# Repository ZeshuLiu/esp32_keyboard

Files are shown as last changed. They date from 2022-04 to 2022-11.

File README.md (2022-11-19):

# 使用esp32为控制器的机械键盘

## **JOKER60**
`Joker 60` 
### **简介**
Joker60是一把poker配列61键键盘，具有一个fn键和一个pn键。
fn键用于输入第二层的键值，如<kbd>F1</kbd>、<kbd>ESC</kbd>（当左上角键被设置为<kbd>`</kbd>时）\
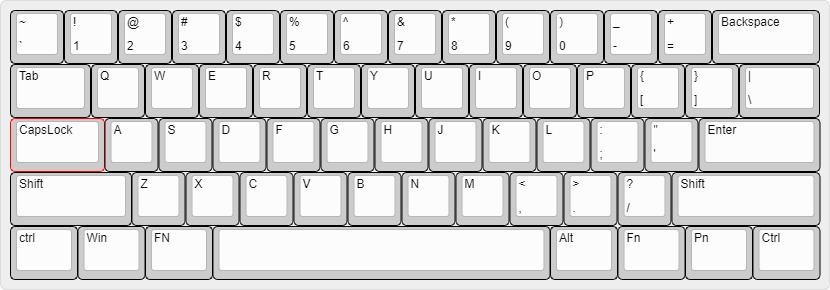
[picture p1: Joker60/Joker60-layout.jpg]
JOKER60 Layout
\
OLED屏幕可以显示当前模式，fn键状态。并且具有每30分钟提醒休息的功能，也可以自己修改源代码进行配置\
具有外接电池位置(PCB上B+、GND) 、外接LED灯或其他部件位置(x_LED)和i2c总线接口（*OLED屏幕使用中、可以串联其他不同地址的i2c设备同时使用*）

## **JOKER60 v2**
`Joker60 v2` 
### **简介**
外形与Joker60完全一致，大部分零件均通用。\
Joker60换用了ch9329芯片，可以支持媒体键（音量增加、减小等）。\
电路板进行了大面积敷铜，使用Kicad进行绘制，工程文件在Joker60_v2文件夹内。\
电路部分经过重新设计可以支持常驻型的usb拓展模块（详见Joker60_v2\usb_ext）并且可以板载电池。\
大小写指示灯更换了位置。

## **MASTER YODA**
`Master Yoda` 
### **简介**
一个小的键盘，可以用来打游戏等。

---
## **如何使用**
## **所需工具**
1. **电烙铁及焊锡等** ***必须***\
    推荐使用可调温电烙铁，普通电烙铁也可以。尽量选择头部比较尖锐的烙铁，方便焊接小零件。*有些元件非常小，因此建议先学习电烙铁使用方法，不要一上来就焊接*
2. **螺丝刀** ***必须***\
    一把3.5mm十字花螺丝刀足够
3. **万用表** ***可选***\
    推荐购买一个万用表，可以方便得检查焊接是否正确。没有也不影响正常组装，但是一旦出现问题难以排查。*万用表质量不需要非常好，便宜的就能够胜任*
4. **镊子** ***可选但是强烈推荐***\
    部分零件非常小，除非你的手特别灵活或者你特别闲脾气又好否则没有镊子你会气死。
5. **小刀** ***可选***\
    用来修整3D打印带来的毛边等。小号的壁纸刀最好。
6. **电线** ***v1.0版本必须***\
    用来飞线。建议使用26AWG粗细的。
7. **BOM表上的其他零件** ***必须***\
    [JOKER60 BOM](https://github.com/LiuZSChina/esp32_keyboard/blob/main/Joker60/01/BOM_PCB_Joker60_ver1_2022-04-18.csv)。除了芯片类的东西比如螺丝、二极管等尽量多买几个，*不建议买正好数量，尤其是螺丝*。建议在立创商城搜索相关零件，如果去淘宝购买注意要购买针脚一样的（***USB接口和开关是重点***）否则装不上。（当然我是在淘宝买的，比较便宜 **:D**

---
###  **PCB部分**
Gerber文件：
1. [JOKER60 PCB](https://github.com/LiuZSChina/esp32_keyboard/blob/main/Joker60/01/Gerber_PCB_Joker60_ver1.zip) 
2. [JOKER60_v2 PCB](https://github.com/LiuZSChina/esp32_keyboard/blob/main/Joker60_v2/Joker60_v2_gerber/Joker60_v2_gerber_1026.zip) \
大部分PCB定制厂商都支持直接使用Gerber文件制作。推荐制作1.6mm厚度。
### **外壳、定位板部分**
外壳、定位板文件：
1. [JOKER60 外壳](https://github.com/LiuZSChina/esp32_keyboard/tree/main/Joker60/3D/ver1.0)\
-定位板推荐使用1.5mm厚度。不锈钢、亚克力等都可以，但是手感不同。样机使用不锈钢、1.5mm激光切割\
-外壳为stl文件、可以直接进行3D打印。打印后压入热熔螺母（M3、外径4.3mm，长度4mm）（需要使用电烙铁进行操作）\
-（可选）亚克力推荐使用2.5mm左右材料进行制造，装饰面板需要与屏幕盖板粘合。不使用这些（亚克力材质的）零件不影响使用，但是电路板会暴露在外，容易积灰。
### **制作**
1. 找厂家生产pcb和外壳等，并购买所需要元件（详见BOM表）
2. 按照BOM表上的元件位号焊接材料，主要二极管（1N4147）有反正之分，请注意区分。
3. 刷入固件，详见各版本介绍中烧录条目。源码中的库需要在Arduino中安装。
### **烧录**
+ **1.0版本**\
    需要将开关打至接通ch340的档位，具体方向和焊接方向有关，可以从电脑设备管理器中查看是否连接上ch340进行判断(***v1.0版本（Gerber_PCB_Joker60_ver1）* 中ch340的tx和rx接线是反的，需要飞线调整，并且用小刀割断pcb上的连线**)\
    将gnd和boot短接后通电(**MasterYoda上采用了按键的形式**)，进入下载模式，使用arduino ide或其他编辑器上传固件（具体方法网上很多教程）。gnd和boot在断开的情况再次断电再通电即可退出下载模式运行键盘程序，此时usb口功能通过开关选择ch340和ch9328在串口调试和USB键盘之间切换，*无法同时使用*

### **快捷键**
+ 开启、关闭内置LED灯：<kbd>Pn</kbd> + <kbd>L</kbd>
+ 重置倒计时：<kbd>Pn</kbd> + <kbd>C</kbd>
+ 连接模式转换：<kbd>Pn</kbd> + <kbd>M</kbd> 并且保持三秒以上

### **2.0版本**
——2022.11——\
修复了大部分问题。\
可以开机切换模式。\
**已知问题：** 
1. 暂无

### **2.1版本**——未发布
*预计更改*：
1. 增加CapsLock指示
2. 蓝牙可以常时连接，可以快速切换在连接的蓝牙设备进行输入或者在连接到usb设备上输入

---
## 历史版本
### **1.0版本**
——2022.4——\
初始发布版本，具有蓝牙和有线连接两种方式。\
**已知问题：** 
1. USB转蓝牙模式会导致死机
2. 更改模式需要重新烧录代码
3. CH340N的rx、tx接反了，需要飞线连接。

## ~~JOKER40~~ **(未完成)**

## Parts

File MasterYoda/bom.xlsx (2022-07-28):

ID | Name | Designator | Footprint | Quantity | Manufacturer Part | Manufacturer | Supplier | Supplier Part | Price
1 | 2焊盘 | U6 | 2焊盘 | 1
2 | POS | P1 | MASTER YODA SWITCH LAYER | 1
3 | 凯华热插拔二极管KBLADE COPY | K16,K2,K3,K4,K5,K6,K7,K8,K9,K10,K11,K12,K13,K14,K15,K17,K18,K20 | 凯华热插拔-单色灯反贴-带二极管-KAILH-IN4148-3528 | 18 |  | Kailh(凯华) |  | C400228 | 2.99
4 | D-W080508W1-KS2 | LED1,LED2 | LED-0805 | 2 | D-W080508W1-KS2 | ARKLED | LCSC | C130115 | 0.2531
5 | Switch,3*6*2.5Plastic | SW1,SW2 | SW-SMD_L6.1-W3.6-LS8.0 | 2 | Switch,3*6*2.5Plastic head white,260G, 0.25mm,SMD | BBJ | LCSC | C71857 | 0.151
6 | TYPE-C-16M-0232MD | USB1 | USB-C-SMD_TYPE-611-T3-W | 1 | TYPE-C-16M-0232MD | USAKRO(美韩) | LCSC | C2798171 | 1.1996
7 | TP5400 | U2 | SOIC-8_L5.0-W4.0-P1.27-LS6.0-BL-EP | 1 | TP5400 | TOPPOWER | LCSC | C24154 | 1.4977
8 | 1K | R18 | R0805 | 1 | 0805W8F1101T5E | UniOhm | LCSC | C17375 | 0.0151
9 | 22uF | C5,C8 | C0805 | 2 | EMK316ABJ226KL-T | Taiyo Yuden | LCSC | C319197 | 0.4
10 | 100nF | C10,C4 | C0805 | 2 | CL21B104KBCNNNC | SAMSUNG | LCSC | C1711 | 0.0302
11 | SS34_C432300 | D1 | SMA_L4.4-W2.8-LS5.4-RD | 1 | SS34 | LGE | LCSC | C432300 | 0.4056
12 | 10uH | L1 | IND-SMD_L5.0-W5.0_SWPA5040S | 1 | TMPC0402HP-100MG-Z02 | TAITEC | LCSC | C305203 | 1.3382
13 | 10uF | C11 | C0805 | 1 | 0805F106M160NT | FH | LCSC | C90545 | 0.1135
14 | 47uF | C12 | C0805 | 1 | TC211A476K010A | Sunlord | LCSC | C112100 | 1.0926
15 | 10k | R24,R25,R6,R10,R8,R9,R7,R2,R4,R3,R1 | R0805 | 11
16 | 1k | R26 | R0805 | 1
17 | 1.1K | R17 | R0805 | 1 | 0805W8F1101T5E | UniOhm | LCSC | C17375 | 0.0151
18 | 22u | C6,C9 | C0805 | 2
19 | 0.1u | C7,C2,C3 | C0805 | 3
20 | 3.3k | R5 | R0805 | 1
21 | B772_C116605 | Q1 | SOT-89-3_L4.5-W2.5-P1.50-LS4.2-BR | 1 | B772 | SK | LCSC | C116605 | 0.3641
22 | 1u | C1 | C0805 | 1
23 | PH2.0 2PIN 卧贴 | P2 | CONN-SMD_PH2.0-2P-WT | 1 | PH2.0 2pin 卧贴 | null | LCSC | C9900004948
24 | ESP32-WROOM-32UE(8MB) | U1 | WIFI-SMD_ESP32-WROOM-32UE | 1 | ESP32-WROOM-32UE(8MB) | Espressif Systems | LCSC | C701345 | 28.01
25 | AMS1117S-3.3 | U4 | SOT-223-4_L6.5-W3.5-P2.30-LS7.0-TR | 1 | AMS1117S-3.3 | JSMSEMI | LCSC | C917152 | 0.6346
26 | CH9328 | U5 | SOP-16_L10.0-W3.9-P1.27-LS6.0-BL | 1 | CH9328 | WCH | LCSC | C82452 | 7.02
27 | 510 | R14,R32,R21,R20,R30,R31,R11,R19,R22,R29,R12,R16,R15,R23,R28,R33,R27,R34 | R0805 | 18
28 | _X001F_MSK-12D191P2T | U3 | SW-TH_MSK-12D191P2T | 1 | _x005F_x001F_MSK-12D191P2T | null | LCSC | C9900016029
定位板
ID | Name | Designator | Footprint | Quantity | Manufacturer Part | Manufacturer | Supplier | Supplier Part | Price
1 | 100pf | C1,C2 | C0805 | 2
2 | D-W080508W1-KS2 | LED1,LED2,LED3,LED4,LED5,LED6,LED7,LED8,LED9,LED10,LED11,LED12,LED13,LED14,LED15,LED16,LED17,LED18,LED19,LED20,LED21,LED22,LED23,LED24,LED25,LED26,LED27,LED28,LED29,LED30,LED31,LED32,LED33,LED34,LED35,LED36,LED37,LED38,LED39,LED40,LED41,LED42,LED43 | LED-0805 | 43 | D-W080508W1-KS2 | ARKLED | LCSC | C130115 | 0.2531
3 | FJ3461AH | LED44 | LED-SEG-TH_12P-L30.0-W14.0-P2.54-S10.16-BL | 1 | FJ3461AH | ReliaPro | LCSC | C10708 | 3.66
4 | POS | P1 | MASTERYODA——POS1 | 1
5 | 510 | R1,R2,R3,R4,R5,R6,R7,R8,R9,R10,R11,R12,R13,R14,R15,R16,R17,R18,R19,R20,R21,R22,R23,R24,R25,R26,R27,R28,R29,R30,R31,R32,R33,R34,R35,R36,R37,R38,R39,R40,R41,R42,R43 | R0805 | 43
6 | 10k | R44,R45 | R0805 | 2
7 | 2焊盘 | U1,U3 | 2焊盘 | 2
8 | TM1637 | U2 | SOP-20_L12.8-W7.5-P1.27-LS10.4-BL | 1 | TM1637 | TM | LCSC | C20001 | 1.2253

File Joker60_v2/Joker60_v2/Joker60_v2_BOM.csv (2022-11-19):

Comment | Description | Designator | Footprint | LibRef | Pins | Quantity | PartNumber | url
1uF | desc | C1, | C_0805_2012Metric_Pad1.18x1.45mm_HandSolder | libref | 2 | 1
0.1uF | desc | C2,C3,C5,C7,C8, | C_0805_2012Metric_Pad1.18x1.45mm_HandSolder | libref | 2 | 5
22uF | desc | C4,C6, | C_0805_2012Metric_Pad1.18x1.45mm_HandSolder | libref | 2 | 2
LED | desc | D33,D49,D57,D65, | LED_0805_2012Metric_Pad1.15x1.40mm_HandSolder | libref | 2 | 4
10K | desc | R1,R2,R3,R4,R5,R6,R7,R8,R9,R12, | R_0805_2012Metric_Pad1.20x1.40mm_HandSolder | libref | 2 | 10
3.3K | desc | R10,R14, | R_0805_2012Metric_Pad1.20x1.40mm_HandSolder | libref | 2 | 2
ESP32-WROOM-32U | desc | U1, | ESP32-WROOM-32U | libref | 39 | 1
CH340N | desc | U2, | SOIC-8_3.9x4.9mm_P1.27mm | libref | 8 | 1
AMS1117-3.3 | desc | U3, | SOT-223-3_TabPin2 | libref | 4 | 1
CH9329 | desc | U4, | SOP-16_3.9x9.9mm_P1.27mm | libref | 16 | 1
0.1uF | desc | C9,C13, | C_0805_2012Metric_Pad1.18x1.45mm_HandSolder | libref | 2 | 2
22uF | desc | C10,C11, | C_0805_2012Metric_Pad1.18x1.45mm_HandSolder | libref | 2 | 2
10uF | desc | C12, | C_0805_2012Metric_Pad1.18x1.45mm_HandSolder | libref | 2 | 1
47uF | desc | C14, | C_0805_2012Metric_Pad1.18x1.45mm_HandSolder | libref | 2 | 1
LL4148 | desc | D1,D2,D3,D4,D5,D6,D7,D8,D9,D10,D11,D12,D13,D14,D15,D16,D17,D18,D19,D20,D21,D22,D23,D24,D25,D26,D27,D28,D29,D30,D31,D32,D34,D35,D36,D37,D38,D39,D40,D41,D42,D43,D44,D45,D46,D47,D48,D50,D51,D52,D53,D54,D55,D56,D58,D59,D60,D61,D62,D63,D64, | D_MiniMELF | libref | 2 | 61
ss34 | desc | D66, | D_SMA_Handsoldering | libref | 2 | 1
Conn_01x02_MountingPin | desc | J2,J3, | Molex_CLIK-Mate_502494-0270_1x02-1MP_P2.00mm_Horizontal | libref | 4 | 2
10uH | desc | L1, | L_Wuerth_HCI-5040 | libref | 2 | 1
Q_NMOS_GSD | desc | Q1, | SOT-23 | libref | 3 | 1
Q_PMOS_GSD | desc | Q2,Q3, | SOT-23 | libref | 3 | 2
10K | desc | R11,R13, | R_0805_2012Metric_Pad1.20x1.40mm_HandSolder | libref | 2 | 2
500k | desc | R15,R16, | R_0805_2012Metric_Pad1.20x1.40mm_HandSolder | libref | 2 | 2
1K | desc | R17, | R_0805_2012Metric_Pad1.20x1.40mm_HandSolder | libref | 2 | 1
5.1K | desc | R18, | R_0805_2012Metric_Pad1.20x1.40mm_HandSolder | libref | 2 | 1
tp5400 | desc | U7, | SOIC-8_3.9x4.9mm_P1.27mm | libref | 8 | 1
Through Hole Items
Cherry_MX | desc | S1,S2,S3,S4,S5,S6,S7,S8,S9,S10,S11,S12,S13,S14,S15,S16,S17,S18,S19,S20,S21,S22,S23,S24,S25,S26,S27,S28,S29,S30,S31,S32,S34,S35,S36,S37,S38,S39,S40,S41,S42,S43,S44,S45,S46,S47,S48,S50,S51,S52,S53,S54,S55,S56,S58,S59,S60,S61,S62,S63,S64, | Cherry-MX_PCB-Mounted | libref | 5 | 61
Oled_0.96_4P | desc | U5, | OLED_4P | libref | 4 | 1
6.25u卫星轴 | desc | U6, | 6.25卫星轴 | libref | 4 | 1
2U卫星轴 | desc | U8,U9,U10, | 2U卫星轴 | libref | 4 | 3
TestPoint_2Pole | desc | EN1,BOOT1,POWER1, | TestPoint_2Pads_Pitch2.54mm_Drill0.8mm | libref | 2 | 3
SW_SPDT | desc | SW2, | SW_CuK_OS102011MA1QN1_SPDT_Angled | libref | 5 | 1
5.8*5.8 | desc | Sw1, | sw5.8_5.8 | libref | 6 | 1
M3_BOLT | desc | Bolt1,Bolt2,Bolt3,Bolt4,Bolt5,Bolt6,Bolt7,Bolt8,Bolt9,Bolt10, | M3 BOLT | libref | 1 | 10
weldpoint | desc | w**,w**,w**,w**, | weldpoint | libref | 1 | 4
USB_B_Mini | desc | J1, | USB_Micro-B_Wuerth_629105150521_CircularHoles | libref | 11 | 1
5.8*5.8 | desc | Sw3, | sw5.8_5.8 | libref | 6 | 1

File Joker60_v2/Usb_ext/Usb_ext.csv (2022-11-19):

Source: | D:\Data\역랙\Joker60_v2\Usb_ext\Usb_ext.kicad_sch
Date: | 2022/11/1 21:55
Tool: | Eeschema (6.0.7)
Generator: | C:\Program Files\KiCad\6.0\bin\scripting\plugins/bom_csv_grouped_by_value_with_fp.py
Component Count: | 24
Ref | Qnty | Value | Cmp name | Footprint | Description | Vendor
Bolt1, Bolt2, | 2 | M3_BOLT | M3_BOLT | Jimmy_Library:M3 BOLT
C1, C2, C5, | 3 | 10uF | C | Capacitor_SMD:C_0805_2012Metric_Pad1.18x1.45mm_HandSolder | Unpolarized capacitor
C3, C4, C6, | 3 | 100nF | C | Capacitor_SMD:C_0805_2012Metric_Pad1.18x1.45mm_HandSolder | Unpolarized capacitor
D1, | 1 | Port2 | LED | LED_SMD:LED_0805_2012Metric_Pad1.15x1.40mm_HandSolder | Light emitting diode
D2, | 1 | Port3 | LED | LED_SMD:LED_0805_2012Metric_Pad1.15x1.40mm_HandSolder | Light emitting diode
D3, | 1 | HUB | LED | LED_SMD:LED_0805_2012Metric_Pad1.15x1.40mm_HandSolder | Light emitting diode
J1, | 1 | USB_A_Port2 | USB_A | Connector_USB:USB_A_Molex_67643_Horizontal | USB Type A connector
J2, | 1 | USB_B_Mini | USB_B_Mini | Connector_USB:USB_Micro-B_Wuerth_629105150521_CircularHoles | USB Mini Type B connector
J3, | 1 | Port3 | Conn_01x04_Shielded | Connector_JST:JST_PH_S4B-PH-SM4-TB_1x04-1MP_P2.00mm_Horizontal | Generic shielded connector, single row, 01x04, script generated (kicad-library-utils/schlib/autogen/connector/)
R1, | 1 | 2.7k | R | Resistor_SMD:R_0805_2012Metric_Pad1.20x1.40mm_HandSolder | Resistor
R2, R4, R5, | 3 | 100k | R | Resistor_SMD:R_0805_2012Metric_Pad1.20x1.40mm_HandSolder | Resistor
R3, | 1 | 47k | R | Resistor_SMD:R_0805_2012Metric_Pad1.20x1.40mm_HandSolder | Resistor
R6, R7, R8, | 3 | 330 | R | Resistor_SMD:R_0805_2012Metric_Pad1.20x1.40mm_HandSolder | Resistor
U1, | 1 | FE1.1s | FE1.1s | Package_SO:SSOP-28_3.9x9.9mm_P0.635mm | USB 2.0 High Speed 4-Port Hub Controller, SSOP-28
Y1, | 1 | 12Mhz | Crystal | Crystal:Crystal_SMD_HC49-SD_HandSoldering | Two pin crystal

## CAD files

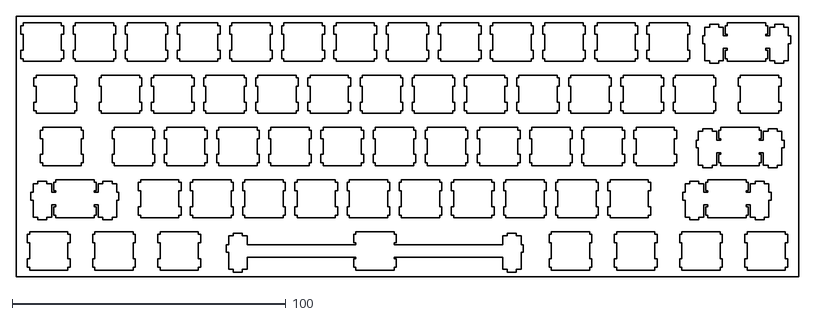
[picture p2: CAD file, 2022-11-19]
Joker60_v2/switch.dxf
285.7 x 95.2

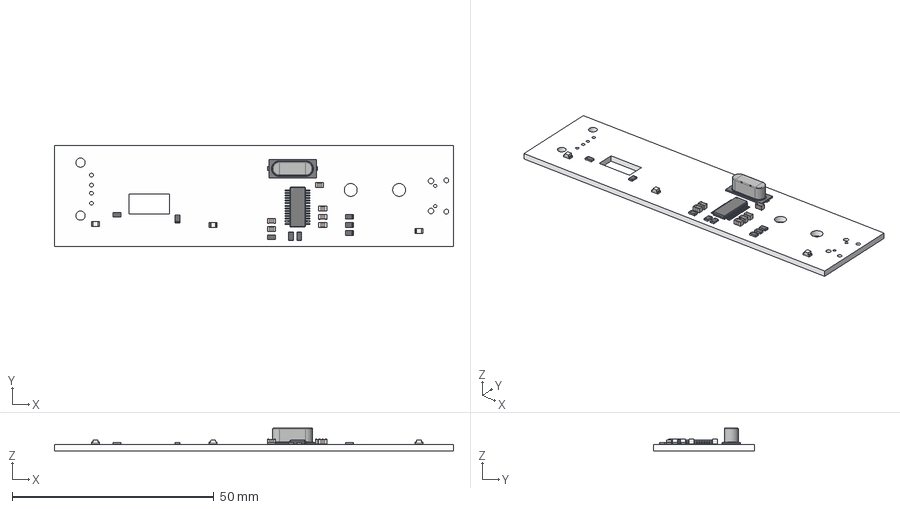
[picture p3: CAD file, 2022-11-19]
Joker60_v2/Usb_ext/Usb_ext.step
99.0 x 25.0 x 5.65 mm
Usb_ext PCB

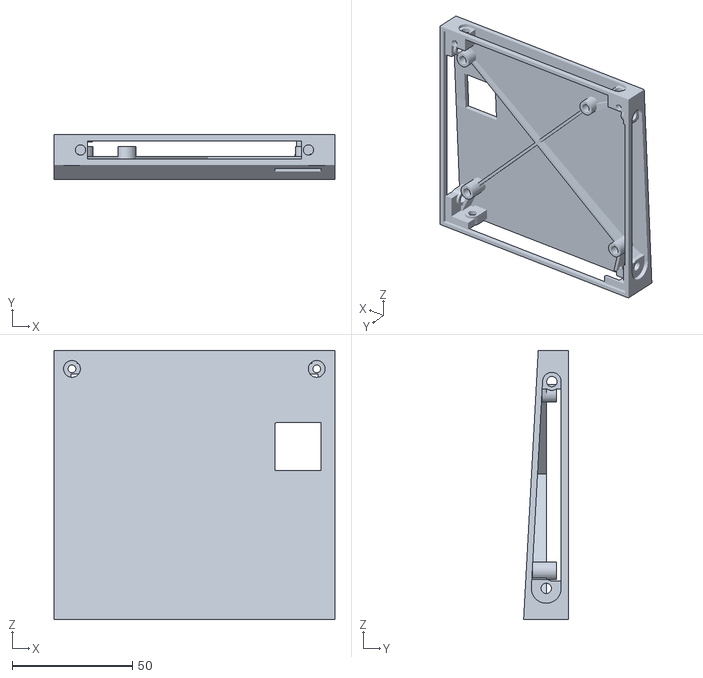
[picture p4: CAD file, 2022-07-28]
MasterYoda/3D/底壳.STL
116.6 x 18.6 x 111.8

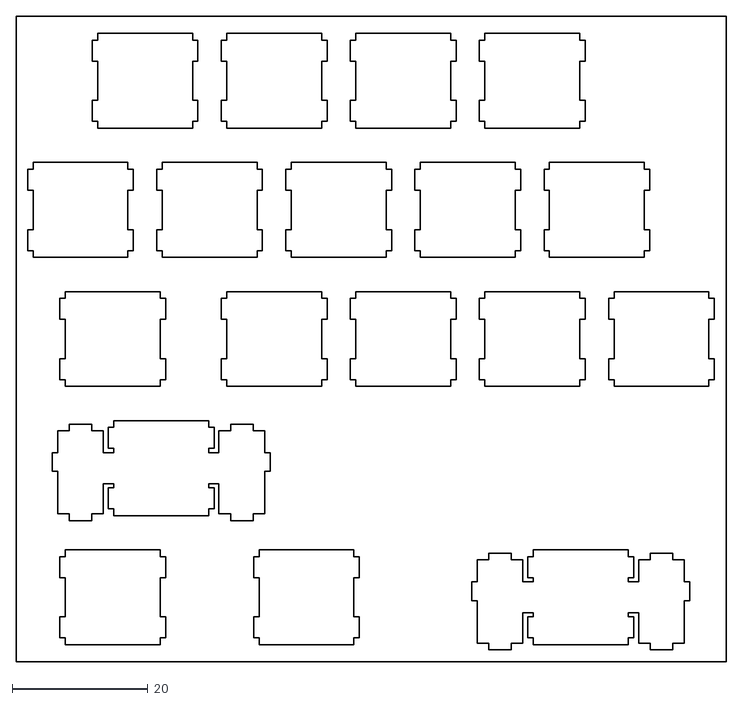
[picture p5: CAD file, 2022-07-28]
MasterYoda/a506ab4adc3b220c52be235e0404b13349fdde59_switch.dxf
104.8 x 95.2

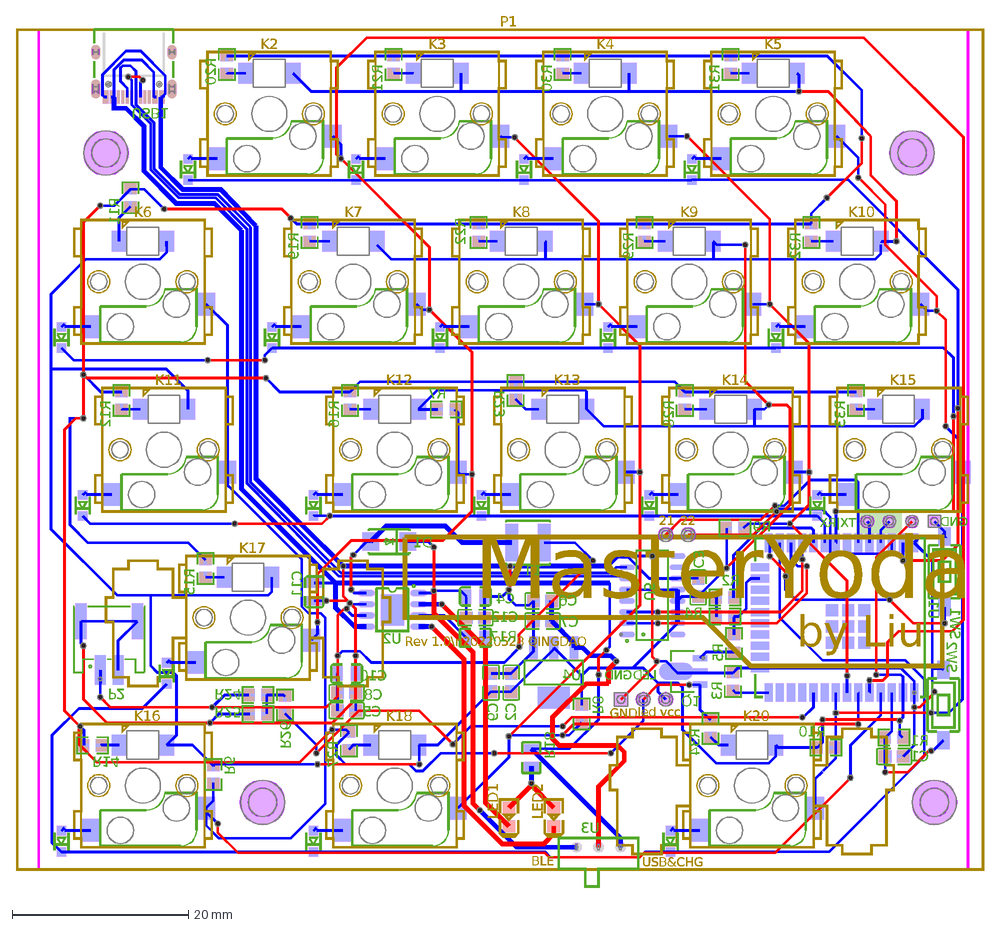
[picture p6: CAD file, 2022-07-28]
MasterYoda/PCB_MasterYoda1_2022-06-14.dxf
LED
GND
TX|RX
MasterYoda
by Liu
Rev 1.0\n20220528 QINGDAO
vcc
led
22
21
USB&CHG
BLE
P1
K16
K2
K3
K4
K5
K6
K7
K8
K9
K10
K11
K12
K13
K14
K15
K17
K18
K20
LED1
LED2
SW1
SW2
USB1
U2
R18
C5
C8
C10
D1
L1
C11
C4
C12
R24
R25
R26
R17
C6
C7
C2
C9
R6
R10
R8
R9
R7
R2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

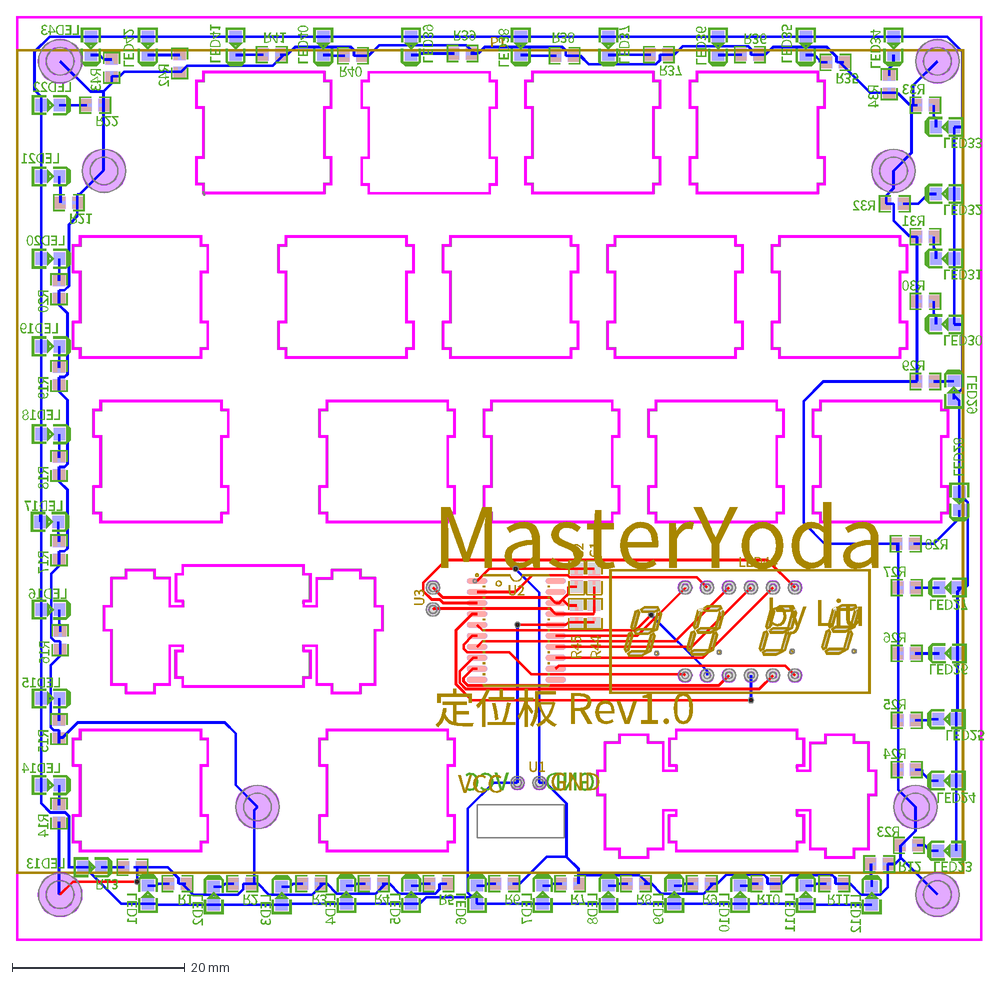
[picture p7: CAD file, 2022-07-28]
MasterYoda/PCB_MasterYoda定位板_2022-06-15.dxf
VCC
GND
MasterYoda
by Liu
定位板 Rev1.0
P1
C1
C2
LED44
R44
R45
U2
U3
U1
LED1
R1
LED2
LED3
LED4
LED5
LED6
LED7
LED8
LED9
LED10
LED11
LED12
LED13
LED14
LED15
LED16
LED17
LED18
LED19
LED20
LED21
LED22
LED23
LED24
LED25
LED26
LED27
LED28
R2
R3
R4
R5
R6
R7
R8
R9
R10
R11
R12
R13
R14
R15
R16
R17
R18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

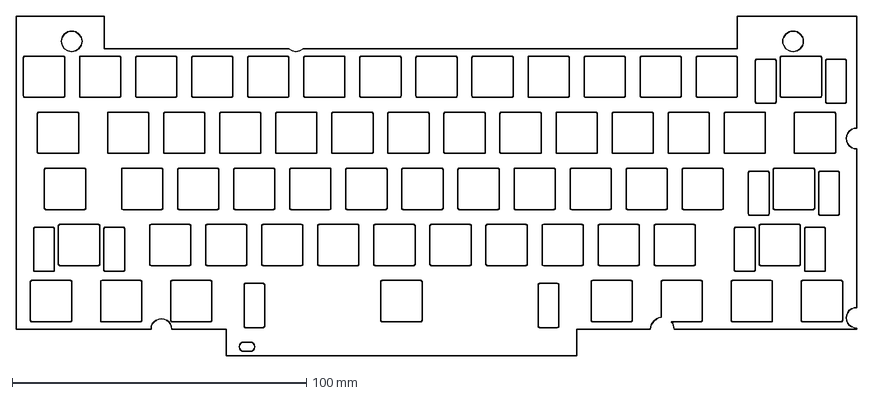
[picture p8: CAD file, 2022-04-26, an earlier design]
Joker60/3D/ver1.0/定位板.DXF
285.8 x 115.2 mm

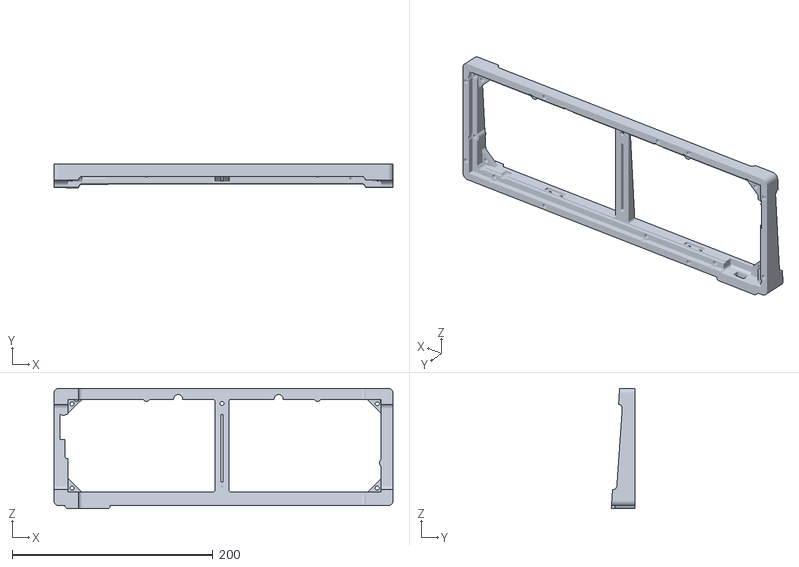
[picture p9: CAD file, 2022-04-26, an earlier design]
Joker60/3D/ver1.0/打印/外壳.STL
337.3 x 23.5 x 119.9

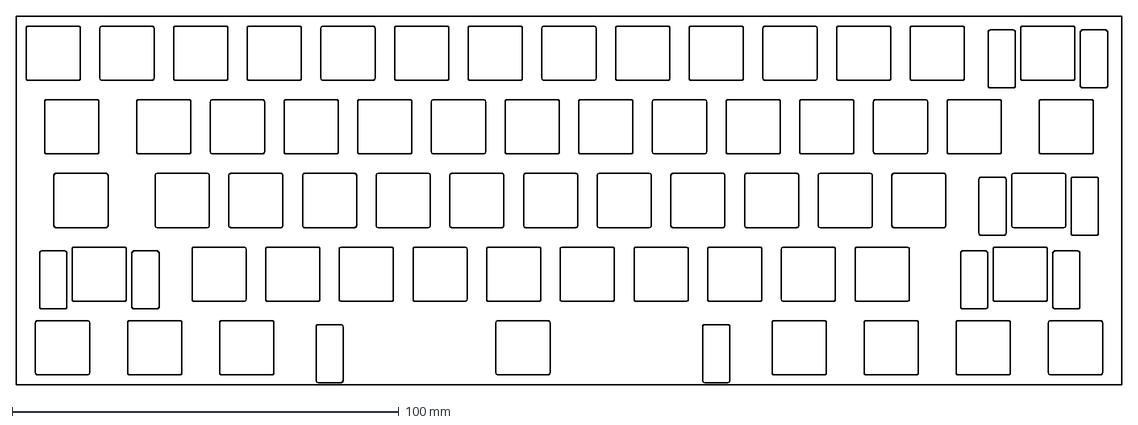
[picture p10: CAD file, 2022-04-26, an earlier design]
Joker60/joker60(61).dxf
285.8 x 95.2 mm

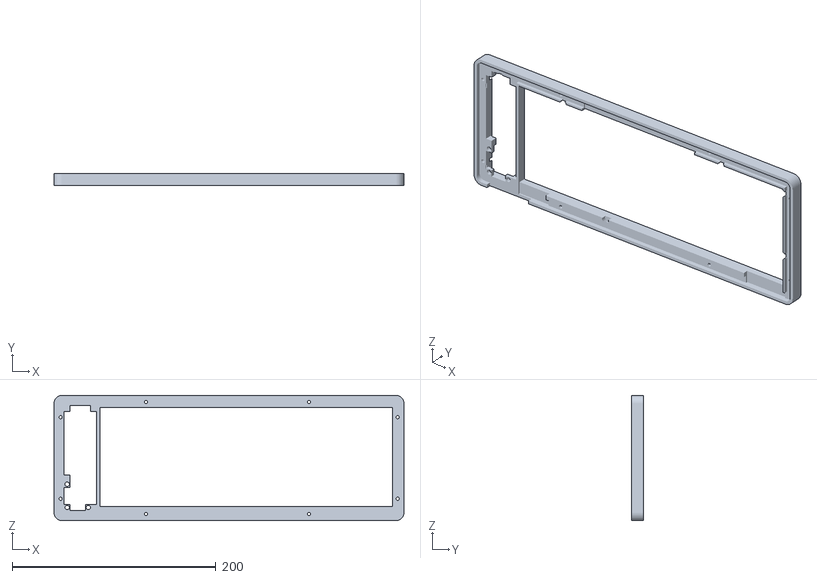
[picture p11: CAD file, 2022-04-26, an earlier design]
Joker60/3D/ver1.0/打印/盖子.STL
343.4 x 12.0 x 122.9

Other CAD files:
Joker60/3D/ver1.0/亚克力/屏幕盖板 装饰.DWG
Joker60/3D/ver1.0/亚克力/底板.DWG
Joker60/3D/ver1.0/亚克力/屏幕盖板.DWG
Joker60_v2/Usb_ext/Usb_ext.SLDPRT
MasterYoda/3D/底壳.DWG

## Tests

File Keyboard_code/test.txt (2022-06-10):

test !!!!if
working? 
yes 
why reboot?
no idea
oled not working

seems worked
but no dog

dog is good
here 弄
我觉得这个东西不见得有什么问题
oled 显示有问题了
不知道为什么

去掉了延时之后
queshi gengjai跟手了，但是不知为什么oled有问题
每个人都希望他好用
好了现在

修好了OLED显示功能，同时提高了轮询率。
good！

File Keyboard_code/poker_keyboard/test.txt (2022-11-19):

qqqqqqqqqqqqqqqqqqqqaaaaaaaaaaaaaaaaaaggaaaaaaaaaaaaaagggagaaaaaaaaaaaaaaaaaaaaaaaaaaaaaaaaaaaaaaaagaaaaagaagagaaggaaaaaaaaggaaaaaaaaaaaaaaagggggggggggggggggggggggggggggggDDDDDDDDDDDDD
dddddddssssdd
haikeyishiyongde ganhuo 
wojuede dongxiqishifeichangbuc

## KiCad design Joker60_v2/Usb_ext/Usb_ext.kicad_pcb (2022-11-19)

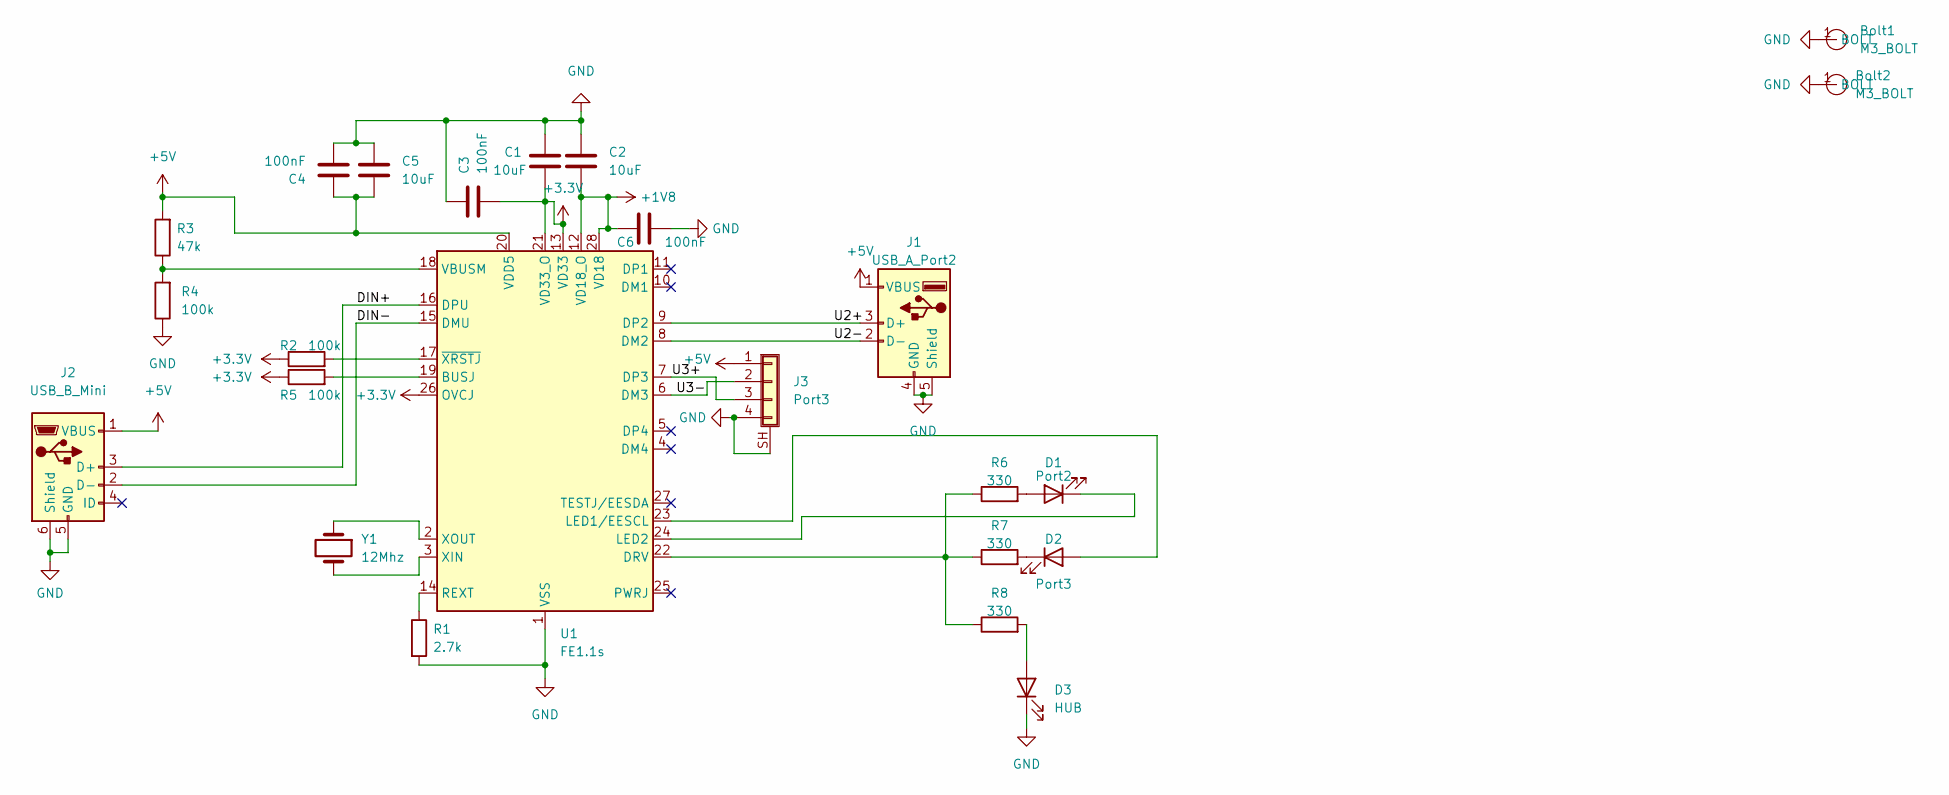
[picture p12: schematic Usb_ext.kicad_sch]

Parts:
Bolt1, Bolt2: M3_BOLT; M3 BOLT
C1, C2, C5: 10uF; C_0805_2012Metric_Pad1.18x1.45mm_HandSolder
C3, C4, C6: 100nF; C_0805_2012Metric_Pad1.18x1.45mm_HandSolder
D1: Port2; LED_0805_2012Metric_Pad1.15x1.40mm_HandSolder
D2: Port3; LED_0805_2012Metric_Pad1.15x1.40mm_HandSolder
D3: HUB; LED_0805_2012Metric_Pad1.15x1.40mm_HandSolder
J1: USB_A_Port2; USB_A_Molex_67643_Horizontal
J2: USB_B_Mini; USB_Micro-B_Wuerth_629105150521_CircularHoles
J3: Port3; JST_PH_S4B-PH-SM4-TB_1x04-1MP_P2.00mm_Horizontal
R1: 2.7k; R_0805_2012Metric_Pad1.20x1.40mm_HandSolder
R2, R4, R5: 100k; R_0805_2012Metric_Pad1.20x1.40mm_HandSolder
R3: 47k; R_0805_2012Metric_Pad1.20x1.40mm_HandSolder
R6, R7, R8: 330; R_0805_2012Metric_Pad1.20x1.40mm_HandSolder
U1: FE1.1s; SSOP-28_3.9x9.9mm_P0.635mm
Y1: 12Mhz; Crystal_SMD_HC49-SD_HandSoldering

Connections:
+1V8: C2.2, C6.1, U1.12 (VD18_O), U1.28 (VD18)
+3.3V: C1.2, C3.2, R2.1, R5.1, U1.13 (VD33), U1.21 (VD33_O), U1.26 (OVCJ)
+5V: C4.1, C5.2, J1.1 (VBUS), J2.1 (VBUS), J3.1, R3.2, U1.20 (VDD5)
/DIN+: J2.3 (D+), U1.16 (DPU)
/DIN-: J2.2 (D-), U1.15 (DMU)
/U2+: J1.3 (D+), U1.9 (DP2)
/U2-: J1.2 (D-), U1.8 (DM2)
/U3+: J3.3, U1.7 (DP3)
/U3-: J3.2, U1.6 (DM3)
GND: Bolt1.1 (BOLT), Bolt2.1 (BOLT), C1.1, C2.1, C3.1, C4.2, C5.1, C6.2, D3.1 (K), J1.4 (GND), J1.5 (Shield), J2.5 (GND), J2.6 (Shield), J3.4, J3.SH (Shield), R1.2, R4.1, U1.1 (VSS)
unnamed: D1.1 (K), U1.24 (LED2)
unnamed: D1.2 (A), R6.2
unnamed: D2.1 (K), R7.2
unnamed: D2.2 (A), U1.23 (LED1/EESCL)
unnamed: D3.2 (A), R8.2
unnamed: R1.1, U1.14 (REXT)
unnamed: R2.2, U1.17 (~XRSTJ)
unnamed: R3.1, R4.2, U1.18 (VBUSM)
unnamed: R5.2, U1.19 (BUSJ)
unnamed: R6.1, R7.1, R8.1, U1.22 (DRV)
unnamed: U1.2 (XOUT), Y1.1
unnamed: U1.3 (XIN), Y1.2

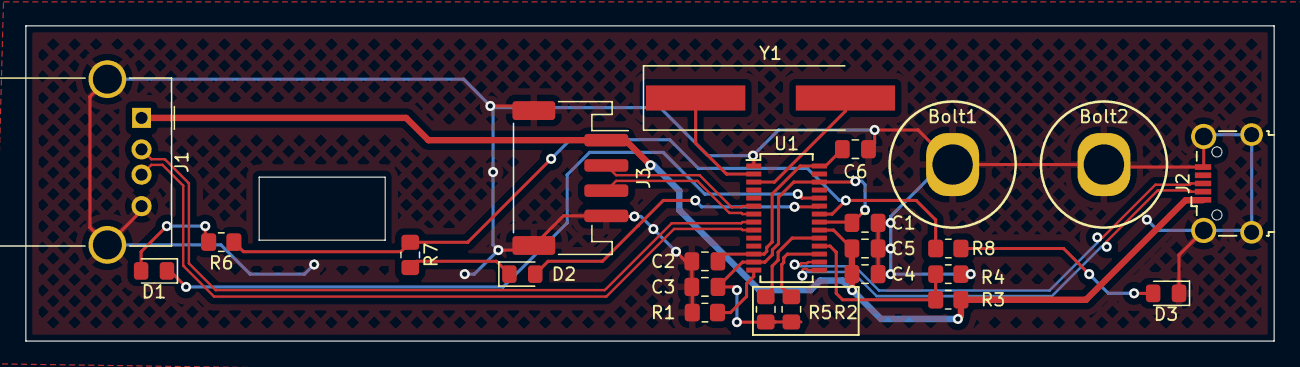
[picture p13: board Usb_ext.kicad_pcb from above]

Board: 2 copper layers, 99.0 x 25.0 mm, 24 parts (0 on the bottom side), 22 nets.

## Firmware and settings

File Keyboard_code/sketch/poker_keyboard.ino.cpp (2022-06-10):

#line 1 "c:\\Users\\liuzeshu\\Desktop\\esp32_keyboard\\v1.0\\poker_keyboard\\poker_keyboard.ino"
# include "poker_keyboard.h"
# include "poker_bt.h"
# include <BleKeyboard.h>
# include <Wire.h>
# include "keyboard_self.h"
# include <Arduino.h>
# include "pcf8575.h"
# include "scan.h"
# include "joker_usb.h"
# include "oled_buff.h"
# include "save.h"

void setup() {
  // DBG 设置
  Serial.begin(115200);
  Serial.println("Joker setting up!");
  delay(100);

  //读取保存的数据
  load_config();
  DFT_BOOT_MODE = Keyboard_Config.BOOT_MODE ;
  Serial.println(String(DFT_BOOT_MODE));
  Serial.println(String(Keyboard_Config.Version_KBD));
  // I2c 设置
  Wire.begin(21,22);
  Serial.println("I2C SET!");

  //初始化扫描工作
  scan_start();
  Serial.println("SCAN SET!");

  // 9328USB输出
  Serial2.begin(115200, SERIAL_8N1, 17, 16); 
  delay(100);
  Serial.println("USB SET!");

  //键盘硬件设置
  keyboard_setup();
  Oled_Start();
  LineDisp("      Joker 60 by LiuZS      ",3);
  LineDisp("====Started!====",0);
  display.drawString(0,0 ,"Joker On !");
  display.display();
  //LineDisp("                              1.0",4);
  delay(200);
  LineDisp(" ",3);
  Serial.println("Joker setted up!");


  if(DFT_BOOT_MODE == 0){
    joker_usb_start();
    //joker_usb_work();
  }
  if(DFT_BOOT_MODE == 1){
    joker_bt_start();
  }
  cnt_start();
}

void loop() {
  // put your main code here, to run repeatedly:

  delay(1000);
}

#line 1 "c:\\Users\\liuzeshu\\Desktop\\esp32_keyboard\\v1.0\\poker_keyboard\\joker_usb.ino"
#include "joker_usb.h"
#include "scan.h"
#include "oled_buff.h"
#include "keyboard_self.h"
#include "poker_bt.h"
#include "save.h"
#include "esp32-hal.h"


void joker_usb_test(){
    if (key_code[2] == 0x00){
        key_code[2] = KEY_USB_A;
        Serial.println("set");
    }
    delay(100);
    Serial2.write(key_code,8);

    key_code[2] = 0x00;
    delay(1000);
    Serial2.write(key_code,8);
    
    Serial.println("sending");
    
}

void joker_usb_work(void *pvParameters){
    bool start_flag = 0;
    bool usb_send = 0;
    for (int i = 0; i < 8; i++)
    {
        key_code[i] = 0x00;
    }
    LineDisp("<MODE>===========USB", ble_line);
    LineDisp("<FN>----------------------------OFF", fn_line);
    int start_time = micros();
    
    for (;;){
        

        key_scan();

        //PN按下
        if(pn_stat){//pn被按下
            if ((key_press[LED_ROW][LED_COL]==0)&&(filter_key_press[LED_ROW][LED_COL]==1)){ //LED 控制
                if(!LED_STAT){
                    open_inter_led();
                    //draw_dog();
                }
                else{
                    close_inter_led();
                }
            }//LED 控制

            //画dog
            if ((key_press[DOG_ROW][DOG_COL]==0)&&(filter_key_press[DOG_ROW][DOG_COL]==1)){ 
                if(oled_mode!=1){
                    oled_mode = 1;
                    draw_dog();
                }
                else{
                    oled_mode = 0;
                }
            }
            //dog结束

            //MODE 控制
            if((key_press[MODE_ROW][MODE_COL]==0)&&(filter_key_press[MODE_ROW][MODE_COL]==1)){ // 第一次按下
                USB_to_change_mode = 1; 
                USB_chang_mode_time = millis();
                LineDisp("<MODE>===========CHG", ble_line);
            }
            if ((key_press[MODE_ROW][MODE_COL]==0)&&USB_to_change_mode&&((millis()-USB_chang_mode_time)>3000)){//连续按压了三秒以上
                USB_to_change_mode = 0;
                joker_usb2bt();
                LineDisp("<MODE>===========BTS", ble_line);
            }
            if(USB_to_change_mode&&(key_press[MODE_ROW][MODE_COL]==1)){//三秒内放开
                USB_to_change_mode = 0;
                LineDisp("<MODE>===========USB", ble_line);
            }
            //MODE 控制

            //重置倒计时
            if ((key_press[cnt_rst_ROW][cnt_rst_COL]==0)&&(filter_key_press[cnt_rst_ROW][cnt_rst_COL]==1)){ 
                rst_cnt_time = 1;
            }
            //重置倒计时


        }
        //PN第一次按下
        if(start_flag&&(pn_stat==0)&&(key_press[PN_ROW][PN_COL] == 0)){//PN第一次按下
            if (DBG_KEYBOARD){
                Serial.println("PN ON!");
            }
            for (int i = 0; i < 8; i++){
                key_code[i] = 0x00;
            }
            usb_send = 1;

            pn_stat = 1;
        }//pn第一次按下
        //PN第一次松开
        if(start_flag&&(pn_stat==1)&&(key_press[PN_ROW][PN_COL] == 1)){//PN第一次松开
            if (DBG_KEYBOARD){
                Serial.println("PN OFF!");
            }
            pn_stat = 0;
            USB_to_change_mode = 0;
        }//pn第一次松开

        // FN 第一次被按下
        if (start_flag&&(key_press[FN_ROW][FN_COL]==0)&&(fn_stat==0)){ 
            if (DBG_KEYBOARD){
            Serial.println("FN IS ON !");
            }
            LineDisp("<FN>-----------------------------ON", fn_line);
            fn_stat = 1;
            for (int ROW = 0; ROW < number_out; ROW++){//行循环判断
                for (int COL = 0; COL < number_in; COL++){//列循环
                    if((old_key_press[ROW][COL]==0)&&(key_press[ROW][COL]==0)&&(USB_LayOut_ALL[ROW][COL]!=USB_LayOut_ALL_FN[ROW][COL])){//键被按下，且此键的键值在fn按下后发生了变化
                        usb_send = 1;
                        if(USB_LayOut_ALL[ROW][COL]!=USB_LayOut_words[ROW][COL]){//是第一位的键值
                                key_code[0] = key_code[0]|USB_LayOut_ALL[ROW][COL];
                        }//是第一位的键值

                        else{//是正常的键值
                            words_change(USB_LayOut_ALL[ROW][COL],1); //松开不是fn的键值
                            words_change(USB_LayOut_words_FN[ROW][COL],0); //按下fn对应的键值
                        }//是正常的键值
                    }// 按下fn后改变键值结束
                }//列循环
            }//行循环判断
        }//fn第一次按下结束
        // FN 第一次被松开
        if (start_flag&&(key_press[FN_ROW][FN_COL]==1)&&(fn_stat==1)){ 
            if (DBG_KEYBOARD){
                Serial.println("FN IS OFF !");
            }
            LineDisp("<FN>----------------------------OFF", fn_line);
            fn_stat = 0;

            /*
            for (int ROW = 0; ROW < number_out; ROW++){//行循环判断
                for (int COL = 0; COL < number_in; COL++){//列循环
                    if((old_key_press[ROW][COL]==0)&&(key_press[ROW][COL]==0)&&(USB_LayOut_ALL[ROW][COL]!=USB_LayOut_ALL_FN[ROW][COL])){//键被按下，且此键的键值在fn按下后发生了变化
                        usb_send = 1;
                        if(USB_LayOut_ALL[ROW][COL]!=USB_LayOut_words[ROW][COL]){//是第一位的键值
                                key_code[0] = key_code[0]&(!USB_LayOut_ALL[ROW][COL]);
                        }//是第一位的键值

                        else{//是正常的键值
                            words_change(USB_LayOut_words_FN[ROW][COL],1); //松开是fn的键值
                            words_change(USB_LayOut_words[ROW][COL],0); //按下fn对应的键值
                        }//是正常的键值
                    }//松开fn改变键值结束
                }
            }
            */
           
        }//fn第一次松开结束
        

        //循环赋值
        for (int ROW = 0; ROW < number_out; ROW++){//循环赋值
            for (int COL = 0; COL < number_in; COL++){
                if (start_flag && (old_key_press[ROW][COL]!=key_press[ROW][COL]) && (filter_key_press[ROW][COL]==key_press[ROW][COL]) &&(!pn_stat)){//键值变化且pn没有按下 并且连续两次按下的一样
                        usb_send = 1;
                    if(USB_LayOut_ALL[ROW][COL]!=USB_LayOut_words[ROW][COL]){//是第一位的键值
                        if(key_press[ROW][COL]==0){//按下
                            if(fn_stat){
                                key_code[0] = key_code[0]|USB_LayOut_ALL_FN[ROW][COL];
                            }
                            else{
                                key_code[0] = key_code[0]|USB_LayOut_ALL[ROW][COL];
                            }
                        }
                        if(key_press[ROW][COL]==1){//松开
                            if(fn_stat){
                                key_code[0] = key_code[0]&(!USB_LayOut_ALL_FN[ROW][COL]);
                            }
                            else{
                                key_code[0] = key_code[0]&(!USB_LayOut_ALL[ROW][COL]);
                            }
                        }
                    }//是第一位的键值

                    else{//是正常的键值
                        if(fn_stat){
                                words_change(USB_LayOut_ALL_FN[ROW][COL],key_press[ROW][COL]);
                            }
                            else{
                                words_change(USB_LayOut_ALL[ROW][COL],key_press[ROW][COL]);
                            }
                    }//是正常的键值

                }//键值变化结束
               
            }//列结束   
        }//行结束
       
       if(!start_flag){
            for (int i = 0; i < number_out; i++){
                for (int j = 0; j < number_in; j++){
                    old_key_press[i][j] = key_press[i][j]; //如果通过了消抖则赋值
                    filter_key_press[i][j] = key_press[i][j]; //无论是否消抖都和前一样赋值
                } 
            }//新旧赋值结束
            start_flag = 1;
        }
        
        //新旧赋值
        for (int i = 0; i < number_out; i++){
            for (int j = 0; j < number_in; j++){
                if (filter_key_press[i][j]==key_press[i][j]){
                     old_key_press[i][j] = key_press[i][j]; //如果通过了消抖则赋值
                }
                filter_key_press[i][j] = key_press[i][j]; //无论是否消抖都和前一样赋值
            } 
        }//新旧赋值结束

        
        //发送按键
        if (usb_send){
            Serial2.write(key_code,8);
            usb_send = 0; //发送后设置为0

            if (DBG_KEYBOARD){
                Serial.println("sending:" + String(key_code[0]));
                Serial.println("Time:" + String(micros()-start_time));
                
            } 
        }
        start_time = micros();
        #ifdef USB_TASK_DELAY
        vTaskDelay(USB_TASK_DELAY);
        #endif
        
    }//循环扫描不会停止
    
}

void words_change(uint8_t word_name, bool stat){
    if(stat==0){//按下
        for (int i = 2; i < 8; i++){//找地方放
            if (key_code[i]==0x00){
                key_code[i]=word_name;
                    break;
            }  
        } 
    }
    if(stat==1){//松开
        for (int i = 2; i < 8; i++){//找地方放
            if (key_code[i]==word_name){
                key_code[i]=0x00;
                break;
            }  
        } 
    }
}


bool joker_usb_start(){
    disableCore0WDT();
    xReturned_usb = xTaskCreatePinnedToCore(joker_usb_work, "JOKER USB WORK", USB_TASK_STACK, NULL, USB_TASK_PRI, &USB_TASK_Handle, USB_TASK_CORE) ; 
    if(xReturned_usb == pdPASS){
        Serial.println("Usb Started!");
        return 1;
    }
    return 0;
}

/*
void joker_usb2bt(){
    Serial.println("CHANGING MODE!");
    joker_bt_start();
    if(USB_TASK_Handle!=NULL){
        USB_TASK_Handle = NULL;
        Serial.println("USB TASK DELETE");
        vTaskDelete(USB_TASK_Handle);
    }
}
*/

void joker_usb2bt(){
    Keyboard_Config.BOOT_MODE = 1;
    save_config();
    ESP.restart();
}

#line 1 "c:\\Users\\liuzeshu\\Desktop\\esp32_keyboard\\v1.0\\poker_keyboard\\keyboard_self.ino"
# include "keyboard_self.h"
# include "poker_keyboard.h"
# include "oled_buff.h"


void keyboard_setup(){
  //初始化io扩展
  //pcf8575_begin();
  pinMode(LED_PIN,OUTPUT);
  open_inter_led();
  invert_disp(1);
  delay(100);
  close_inter_led();
  invert_disp(0);
}

void open_inter_led(){
  digitalWrite(LED_PIN,HIGH);
  LED_STAT = 1;
}
void close_inter_led(){
  digitalWrite(LED_PIN,LOW);
  LED_STAT = 0;
}

void cnt_work(void *pvParameters){
  int start_time = millis();
  int time_pass;
  int cnt_down;
  for (;;){
    if(rst_cnt_time){
      start_time = millis();
      rst_cnt_time = 0;
      vTaskDelay(1000);
    }
    time_pass = millis() - start_time;
    cnt_down = CNT_TIME - time_pass;
    //LineDisp("<COUNT DOWN>---------" + String(cnt_down/60000),5);
    if (cnt_down<=0){
      LineDisp("<Need Rest in>---------NOW!",5);
      invert_disp(1);
    }
    else{
      LineDisp("<Need Rest in>---------" + String(cnt_down/60000),5);
      invert_disp(0);
    }
    vTaskDelay(1000);
  }
}

bool cnt_start(){
  xReturned_cnt = xTaskCreatePinnedToCore(cnt_work, "JOKER CNT WORK", CNT_TASK_STACK, NULL, CNT_TASK_PRI, &CNT_TASK_Handle, CNT_TASK_CORE) ; 
  if(xReturned_cnt == pdPASS){
    return 1;
  }
  return 0;
}


void keyboard_device_test(){
    open_i2c_keyboard_led();
    delay(100);
    close_i2c_caps_led();
    delay(5000);
    close_i2c_keyboard_led();
    delay(100);
    open_i2c_caps_led();
}



#line 1 "c:\\Users\\liuzeshu\\Desktop\\esp32_keyboard\\v1.0\\poker_keyboard\\oled_buff.ino"
#include "oled_buff.h"
# include "Pic.h"
# define HEIGHT_WORDS 9 

void Oled_Start(void){    // 开启oled显示
  display.init();
  display.flipScreenVertically();
  display.setBrightness(OLED_BRIGHT);
}

void LineDisp(String to_print,int line, bool if_clear){
  /*
    if (if_clear){
        for(int i=0; i<buff_size; i++){
            Line_Buff[i] = "";
        }
    }
    Line_Buff[line] = to_print;

    if(oled_mode == 0){
        display.clear();

        for(int i=0; i<buff_size; i++){
            display.drawString(0, HEIGHT_WORDS*i ,Line_Buff[i]);
        }
        display.display();
    }
    */
}

void invert_disp(bool if_invert){
    if (!if_invert){//不反向
        if (oled_invert){//是反向
            display.normalDisplay();
            oled_invert = 0;
        }
    }
    else{//反显
        if (!oled_invert){
            display.invertDisplay();
            oled_invert = 1;
        }
    }
    
}

void draw_dog(){
    if (oled_mode==1){
        display.clear(); //for Clearing the display
        display.drawXbm(0, 0, 128, 64, dog_bmp);
        display.display();
    }
}

#line 1 "c:\\Users\\liuzeshu\\Desktop\\esp32_keyboard\\v1.0\\poker_keyboard\\pcf8575.ino"
#include "pcf8575.h"

void pcf8575_begin(){
    pcf8575_writeAll(word(B11111111,B11111111));
}

void pcf8575_writeAll(uint16_t data) {
  Wire.beginTransmission(pcf_address);
  Wire.write(lowByte(data));
  Wire.write(highByte(data));
  Wire.endTransmission();
}

void pcf8575_readAll() {
    Wire.requestFrom(pcf_address, 16);    // Request 8 bytes from slave device number two
    // Slave may send less than requested
	byte b1 = Wire.read();
	byte b2 = Wire.read();

    if (DBG_KEYBOARD){
        Serial.println("..");
        Serial.println(b1);
	    Serial.println(b2);
    }
    
}

#line 1 "c:\\Users\\liuzeshu\\Desktop\\esp32_keyboard\\v1.0\\poker_keyboard\\poker_bt.ino"
#include "poker_bt.h"
#include "oled_buff.h"
#include "keyboard_self.h"
#include "joker_usb.h"
#include "save.h"

BleKeyboard bleKeyboard(DeviceName, Manufacturer, DevicePower);

void bt_test(){
  int i = 0;
    pinMode(34,INPUT);
    if(DBG_KEYBOARD){
        Serial.println("Starting BLE TEST!");
    }

    bleKeyboard.begin();//Start blekeyboard service
  pinMode(2,OUTPUT);
  //
    for(;;){
    
        if(bleKeyboard.isConnected()&&(!digitalRead(34))) {
            Serial.println("w");
            if(i==0){
              bleKeyboard.press(KEY_W);
              digitalWrite(2,HIGH);
            }
             if(i==1){
               bleKeyboard.releaseAll();
               digitalWrite(2,LOW);
             }

            //bleKeyboard.releaseAll();
            //
            // Below is an example of pressing multiple keyboard modifiers 
            // which by default is commented out. 
            // 
            /* Serial.println("Sending Ctrl+Alt+Delete...");
            bleKeyboard.press(KEY_LEFT_CTRL);
            bleKeyboard.press(KEY_LEFT_ALT);
            bleKeyboard.press(KEY_DELETE);
            delay(100);
            bleKeyboard.releaseAll();
            */
          i = (i+1)%2;
  }
    }
  Serial.println("Waiting 5 seconds...");
  delay(5000);
}

/*
蓝牙工作模式
*/
void bt_work(void *pvParameters){
  if(DBG_KEYBOARD){
        Serial.println("Starting BLE work!");
  }
  LineDisp("-------BLE------", ble_line);
  vTaskDelay(1000);
  bleKeyboard.begin();//Start blekeyboard service
  LineDisp("Waiting for BLE", ble_line);
  
  bool start_flag = 0;
  
//循环扫描
for (;;){
  if (bleKeyboard.isConnected()){//连接上
    bt_stat = 1;

     //第一次先赋值

    if (!start_flag){
      Serial.println("connected!");
      //LineDisp(">========BLE========<", ble_line);
      LineDisp("<MODE>===========BLE", ble_line);
      LineDisp("<FN>-------------------------OFF", fn_line);
    }
    
    //扫描
    key_scan();

    //PN按下
    if(pn_stat){//pn被按下
      if ((key_press[LED_ROW][LED_COL]==0)&&(old_key_press[LED_ROW][LED_COL]==1)){ //LED 控制
        if(!LED_STAT){
          open_inter_led();
        }
        else{
          close_inter_led();
        }
      }//LED 控制
      
      //MODE 控制
      if((key_press[MODE_ROW][MODE_COL]==0)&&(old_key_press[MODE_ROW][MODE_COL]==1)){ // 第一次按下
        bt_to_change_mode = 1; 
        bt_chang_mode_time = millis();
        LineDisp("<MODE>===========CHG", ble_line);
      }
      if ((key_press[MODE_ROW][MODE_COL]==0)&&bt_to_change_mode&&((millis()-bt_chang_mode_time)>3000)){//连续按压了三秒以上
        bt_to_change_mode = 0;
        joker_bt2usb();
        LineDisp("<MODE>===========LIS", ble_line);
      }
      if(bt_to_change_mode&&(key_press[MODE_ROW][MODE_COL]==1)){//三秒内放开
        bt_to_change_mode = 0;
        LineDisp("<MODE>===========BLE", ble_line);
      }
      //MODE 控制

      //重置倒计时
      if ((key_press[cnt_rst_ROW][cnt_rst_COL]==0)&&(old_key_press[cnt_rst_ROW][cnt_rst_COL]==1)){ 
        rst_cnt_time = 1;
      }
      //重置倒计时
    }
    //PN第一次按下
    if(start_flag&&(pn_stat==0)&&(key_press[PN_ROW][PN_COL] == 0)){//PN第一次按下
      if (DBG_KEYBOARD){
        Serial.println("PN ON!");
      }
      for (int i = 0; i < 8; i++){
        bleKeyboard.releaseAll();
      }

      pn_stat = 1;
    }//pn第一次按下
    //PN第一次松开
    if(start_flag&&(pn_stat==1)&&(key_press[PN_ROW][PN_COL] == 1)){//PN第一次松开
      if (DBG_KEYBOARD){
        Serial.println("PN OFF!");
      }
      pn_stat = 0;
    }//pn第一次松开

    // FN 第一次被按下
    if (start_flag&&(key_press[FN_ROW][FN_COL]==0)&&(fn_stat==0)){ 
      if (DBG_KEYBOARD){
        Serial.println("FN IS ON !");
      }
      LineDisp("<FN>--------------------------ON", fn_line);
      fn_stat = 1;

      for (int ROW = 0; ROW < number_out; ROW++){//行循环判断
        for (int COL = 0; COL < number_in; COL++){//列循环
          if((old_key_press[ROW][COL]==0)&&(key_press[ROW][COL]==0)&&(LayOut_ALL[ROW][COL]!=LayOut_ALL_FN[ROW][COL])){//键被按下，且此键的键值在fn按下后发生了变化
            bleKeyboard.release(LayOut_ALL[ROW][COL]);
            bleKeyboard.press(LayOut_ALL_FN[ROW][COL]);
          }
        }
      }
    }//fn第一次按下结束

    if (start_flag&&(key_press[FN_ROW][FN_COL]==1)&&(fn_stat==1)){ // FN 第一次被松开
      if (DBG_KEYBOARD){
        Serial.println("FN IS OFF !");
      }
      LineDisp("<FN>-------------------------OFF", fn_line);
      fn_stat = 0;

      for (int ROW = 0; ROW < number_out; ROW++){//行循环判断
        for (int COL = 0; COL < number_in; COL++){//列循环
          if((old_key_press[ROW][COL]==0)&&(key_press[ROW][COL]==0)&&(LayOut_ALL[ROW][COL]!=LayOut_ALL_FN[ROW][COL])){//键被按下，且此键的键值在fn按下后发生了变化
            bleKeyboard.release(LayOut_ALL_FN[ROW][COL]);
            bleKeyboard.press(LayOut_ALL[ROW][COL]);
          }
        }
      }
    }//fn第一次松开结束
    
    for (int ROW = 0; ROW < number_out; ROW++){//行循环判断
      for (int COL = 0; COL < number_in; COL++){//列循环
          
        //判断键值变化
        if ((!pn_stat)&&start_flag && ( (old_key_press[ROW][COL]!=key_press[ROW][COL]))){ 
          if (DBG_KEYBOARD){
            Serial.println("***["+ String(ROW) + "," + String(COL) + "]:" + String(key_press[ROW][COL])+ "means:" + String(LayOut_ALL[ROW][COL]) );
          }

          //发送按键
          if (LayOut_ALL[ROW][COL]!=0){
            if (key_press[ROW][COL]==0){//如果低电平则按下
              if (fn_stat){
                bleKeyboard.press(LayOut_ALL_FN[ROW][COL]);
              }
              else{
                bleKeyboard.press(LayOut_ALL[ROW][COL]);
              }
            }
            if(key_press[ROW][COL]==1){//高电平则松开
              if (fn_stat){
                bleKeyboard.release(LayOut_ALL_FN[ROW][COL]);
              }
              else{
                bleKeyboard.release(LayOut_ALL[ROW][COL]);
              }
            } 

          }//发送结束
            
        }//判断键值变化结束
        
      }//列循环
    }//行循环   
      //新旧赋值
        for (int i = 0; i < number_out; i++){
            for (int j = 0; j < number_in; j++){
                if (filter_key_press[i][j]==key_press[i][j]){
                     old_key_press[i][j] = key_press[i][j]; //如果通过了消抖则赋值
                }
                filter_key_press[i][j] = key_press[i][j]; //无论是否消抖都和前一样赋值
            } 
        }//新旧赋值结束



  } //连接上
  else{
    delay(10);//没连接上就等着
  }
  #ifdef BT_TASK_DELAY
        vTaskDelay(BT_TASK_DELAY);
        #endif

}//循环扫描不会结束

}//end bt_work

bool joker_bt_start(){
    Serial.println("bt starting!");
    xReturned_bt = xTaskCreatePinnedToCore(bt_work, "JOKER BT WORK", BT_TASK_STACK, NULL, BT_TASK_PRI, &BT_TASK_Handle, BT_TASK_CORE) ; 
    if(xReturned_bt == pdPASS){
        return 1;
    }
    return 0;
}

/*
void joker_bt2usb(){
    Serial.println("CHANGING MODE!");
    bleKeyboard.end();
    joker_usb_start();
    if(BT_TASK_Handle!=NULL){
        BT_TASK_Handle = NULL;
        Serial.println("BT TASK DELETE");
        vTaskDelete(BT_TASK_Handle);
    }
}
*/

void joker_bt2usb(){
    Serial.println("CHANGING MODE!");
    Keyboard_Config.BOOT_MODE = 0; 
    save_config();
    ESP.restart();
}
#line 1 "c:\\Users\\liuzeshu\\Desktop\\esp32_keyboard\\v1.0\\poker_keyboard\\save.ino"
#include <EEPROM.h>
#include "save.h" 

void save_config()
{
    EEPROM.begin(1024);
    uint8_t *p = (uint8_t *)(&Keyboard_Config);
    for (int i = 0; i < sizeof(Keyboard_Config); i++)
    {
        EEPROM.write(i, *(p + i));
    }
    EEPROM.end();
}
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

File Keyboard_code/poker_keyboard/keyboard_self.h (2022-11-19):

#ifndef KEYBOARD_SELF_H
#define KEYBOARD_SELF_H

# include "poker_keyboard.h"
# include <Arduino.h>
# include "pcf8575.h"
# include "Layout.h"


//设备状态
bool LED_STAT = 0;
bool CAP_LED_STAT = 0;

//倒计时
BaseType_t xReturned_cnt;
TaskHandle_t CNT_TASK_Handle = NULL;
#define CNT_TASK_CORE 1
#define CNT_TASK_STACK 2048
#define CNT_TASK_PRI 10
int CNT_TIME = 1800000 ;
//int CNT_TIME = 60000;
bool rst_cnt_time = 0;
# define cnt_line 5
bool cnt_start();

//初始化
void keyboard_setup(void);

//LED设置
//Joker60
# ifndef Ver2
# define LED_PIN 12
# define CAP_LED_PIN P01
# endif
//Joker 60v2
# ifdef Ver2
# define LED_PIN 15
# define CAP_LED_PIN P01
#endif

void open_i2c_keyboard_led(void);
void close_i2c_keyboard_led(void);
void open_i2c_caps_led(void);
void close_i2c_caps_led(void);
void open_inter_led();
void close_inter_led();


//测试
void keyboard_device_test(void);

//IO扩展板地址
//# define io_exp_in_cnt 1
//# define io_exp_out_cnt 3
//int io_expand_input[io_exp_in_cnt] = {P15};
//int io_expand_output[io_exp_out_cnt] = {P0,P1,P2} ; 

byte write_low = B00000000;

#endif

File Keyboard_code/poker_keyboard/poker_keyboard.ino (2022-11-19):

# include "poker_keyboard.h"
# include "poker_bt.h"
# include <BleKeyboard.h>
# include <Wire.h>
# include "keyboard_self.h"
# include <Arduino.h>
# include "pcf8575.h"
# include "scan.h"
# include "joker_usb.h"
# include "save.h"
# include "oled_buff.h"
# include "L_CH932x.h"

#ifdef MasterYoda
  # include "Seg_disp.h"
#endif



void setup() {
  // DBG 设置
  Serial.begin(115200);
  Serial.println("Joker setting up!");
  delay(100);

  //读取保存的数据
  load_config();
  DFT_BOOT_MODE = Keyboard_Config.BOOT_MODE ;
  Serial.println(String(DFT_BOOT_MODE));
  Serial.println(String(Keyboard_Config.Version_KBD));
  // I2c 设置
  #ifdef Joker
  Wire.begin(21,22);
  Serial.println("I2C SET!");
  #endif
  
  //初始化扫描工作
  scan_start();
  Serial.println("SCAN SET!");

  // 9328USB输出
  #ifdef Joker
  #ifndef Ver2
  Serial2.begin(115200, SERIAL_8N1, 17, 16); 
  #endif
  #endif

  // ch9329
  #ifdef Joker
  #ifdef Ver2
  ch9329.begin(16,17,9600);
  #endif
  #endif

  #ifdef MasterYoda
  Serial2.begin(115200, SERIAL_8N1, 16, 17);
  #endif

  delay(100);
  Serial.println("USB SET!");

  //键盘硬件设置
  keyboard_setup();
  Serial.println("Joker setted up!");
  delay(100);
  if(DFT_BOOT_MODE == 0){
    joker_usb_start();
    //joker_usb_work();
  }
  if(DFT_BOOT_MODE == 1){
    joker_bt_start();
  } 
  cnt_start();
}

void loop() {
  delay(1000);// put your main code here, to run repeatedly:
  #ifdef MasterYoda
    tm1637.display(2, (8));
    tm1637.display(3, (8));
    
  #endif
}

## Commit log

2022-03-30 ble dbg
    [partitions.csv]
2022-04-06 Half Worked
    Left half of the keyboard works fine!
    Right remains to be finished!
    [矩阵线图.xlsx]
2022-04-26 Ready to release
    [BOM_PCB_Joker60_ver1_2022-04-18.csv]
2022-06-10 Speed up
    [partitions.csv]
2022-06-20 MasterYoda support！
    [partitions.csv]
2022-07-28 New model--Master Yoda
    An 18-key pad for gaming &numbers typing!
    [BOM_MasterYoda定位板_2022-06-14 副本.xlsx, BOM_MasterYoda定位板_2022-06-14.csv, BOM_PCB_MasterYoda1_2022-06-08.csv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]
2022-08-10 Filter refined&Fn Bug fixed
    Increased filtering step from 3to5, reduced the possibility of giving multi input.
    When quitting Fn-layer, unlike previous version, every key will be released.
    [Layout.h, joker_usb.ino, poker_bt.ino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]
2022-10-17 Filtering Upgrade&Display Fixed
    Now you can have the correct displaying on your device !
    And FAKE responding reduced Greatly!
    Jimmy 20221017
    [joker_usb.ino, keyboard_self.ino, oled_buff.ino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]
2022-11-19 New Model Joker60_V2
    [Joker60_v2-B_Cu.gbr, Joker60_v2-B_Mask.gbr, Joker60_v2-B_Paste.gbr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]
